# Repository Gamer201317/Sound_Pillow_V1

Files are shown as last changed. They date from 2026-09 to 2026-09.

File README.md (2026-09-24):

# Sound_Pillow_V1

Sound Pillow is an 12 key sounboard with aa rotarty encoder 7 sk mini-e and uses kmk firmware

Features:

12 keys
EC11 Rotary encoder for Volume
7 sk mini-e for a little disco
and aa case in the shape of a pillow 

Cad Model:

the case uses glue to fit everything together at the final stage 
it haas 2 sepaaretly printed pieces the bottom where the pcb slides in to and one top hat you put ovr your key

Schermafbeelding 2026-09-24 143343

make in Tinkercad becausee fusion 360 was to difucult 

Pcb:

Here's my PCB! It was made in KiCad. The silkscreen i found on the internet and aded it 
Schermafbeelding 2026-09-24 143409

this is the schematic

Schermafbeelding 2026-09-24 143421

and this is the pcb

and the next time i'm doing something like this i would like to cleaan the schematic up a little bit more

Firmware Overview

This hackpad uses kmk firmware for everything 
the rotary encoder changes thee volume and i didn't use the button
The 12 keys act as f13-f24 and i use https://www.voicemod.net/ as the software  so i can use the macropad as a soundboard  in discord 
and the leds are there for a little disco

Bom 

-12x Cherry MX Switches
12x DSA Keycaps
-2x M3x16mm SHCS Bolts
-5x 1N4148 DO-35 Diodes.
-7x sk mini-e LEDs
-1x EC11 Rotary Encoder
-1x XIAO RP2040
-1x Case (2 printed parts)

and if you're wondering why there is a hole in the top right of the case that's so you can add an acrylic plate or just watch the components

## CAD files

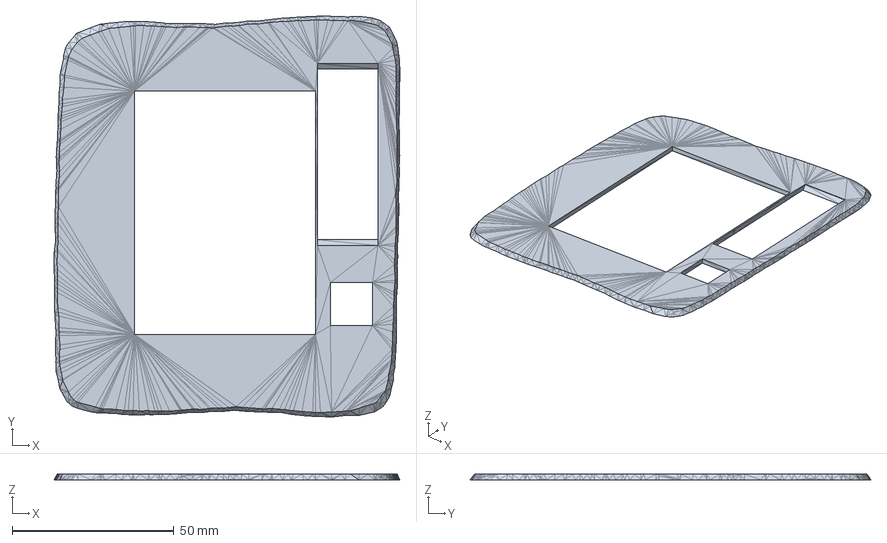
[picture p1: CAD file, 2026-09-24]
Production/Sound_Pillow_Middle.step
106.9 x 123.9 x 1.80 mm

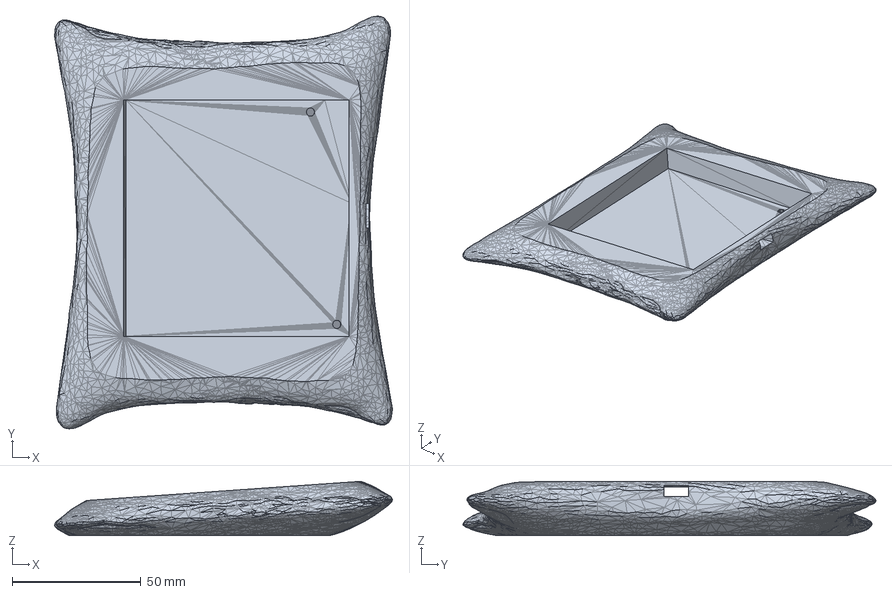
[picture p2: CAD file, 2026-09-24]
Production/Sound_Pillow_Bottom.step
131.2 x 160.1 x 21.1 mm

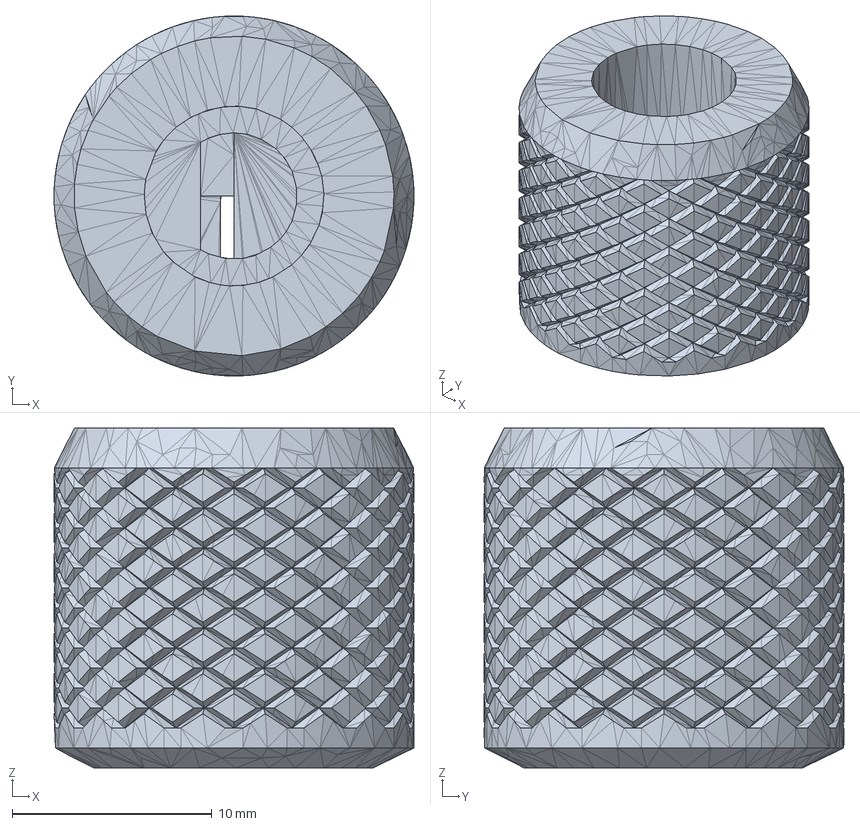
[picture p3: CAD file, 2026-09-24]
Production/Hack Pad Screw.step
18.0 x 18.0 x 17.0 mm
STEP translator 7.5 1.1
STEP translator 7.5 1.2

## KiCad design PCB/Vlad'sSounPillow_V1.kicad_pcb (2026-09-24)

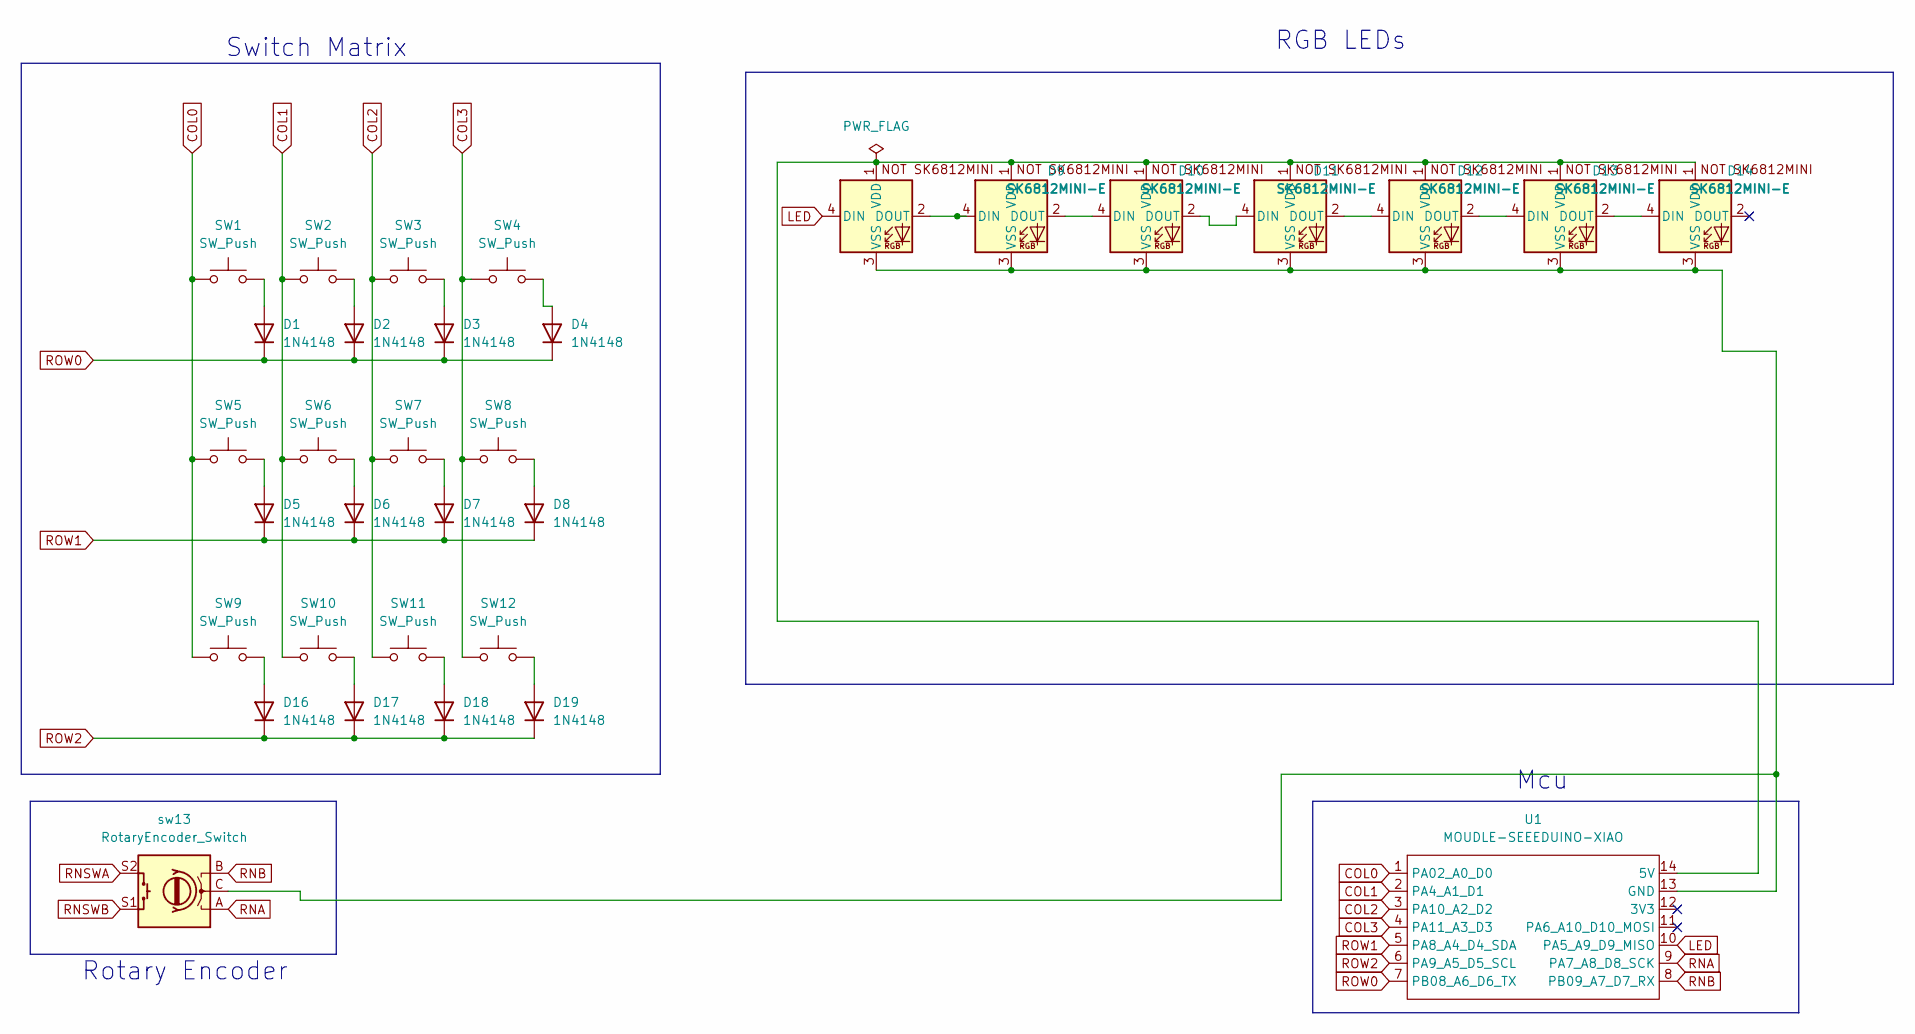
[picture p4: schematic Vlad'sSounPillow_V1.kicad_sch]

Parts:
D1, D2, D3, D4, D5, D6, D7, D8, D16, D17, D18, D19: 1N4148; D_DO-35_SOD27_P7.62mm_Horizontal
D9, D10, D11, D12, D13, D14, D15: SK6812MINI-E; SK6812MINI-E_fixed
SW1, SW2, SW3, SW4, SW5, SW6, SW7, SW8, SW9, SW10, SW11, SW12: SW_Push; SW_Cherry_MX_1.00u_PCB
U1: MOUDLE-SEEEDUINO-XIAO; XIAO-Generic-Hybrid-14P-2.54-21X17.8MM
sw13: RotaryEncoder_Switch; RotaryEncoder_Alps_EC11E-Switch_Vertical_H20mm

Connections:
COL0: SW1.1, SW5.1, SW9.1, U1.1 (PA02_A0_D0)
COL1: SW2.1, SW6.1, SW10.1, U1.2 (PA4_A1_D1)
COL2: SW3.1, SW7.1, SW11.1, U1.3 (PA10_A2_D2)
COL3: SW4.1, SW8.1, SW12.1, U1.4 (PA11_A3_D3)
LED: D9.4 (DIN), U1.10 (PA5_A9_D9_MISO)
unnamed: D1.2 (A), SW1.2
unnamed: D2.2 (A), SW2.2
unnamed: D3.2 (A), SW3.2
unnamed: D4.2 (A), SW4.2
unnamed: D5.2 (A), SW5.2
unnamed: D6.2 (A), SW6.2
unnamed: D7.2 (A), SW7.2
unnamed: D8.2 (A), SW8.2
unnamed: D9.2 (DOUT), D10.4 (DIN)
unnamed: D10.2 (DOUT), D11.4 (DIN)
unnamed: D9.1 (VDD), D10.1 (VDD), D11.1 (VDD), D12.1 (VDD), D13.1 (VDD), D14.1 (VDD), D15.1 (VDD), U1.14 (5V)
unnamed: D9.3 (VSS), D10.3 (VSS), D11.3 (VSS), D12.3 (VSS), D13.3 (VSS), D14.3 (VSS), D15.3 (VSS), U1.13 (GND), sw13.C
unnamed: D11.2 (DOUT), D12.4 (DIN)
unnamed: D12.2 (DOUT), D13.4 (DIN)
unnamed: D13.2 (DOUT), D14.4 (DIN)
unnamed: D14.2 (DOUT), D15.4 (DIN)
unnamed: D16.2 (A), SW9.2
unnamed: D17.2 (A), SW10.2
unnamed: D18.2 (A), SW11.2
unnamed: D19.2 (A), SW12.2
RNA: U1.9 (PA7_A8_D8_SCK), sw13.A
RNB: U1.8 (PB09_A7_D7_RX), sw13.B
RNSWA: sw13.S2
RNSWB: sw13.S1
ROW0: D1.1 (K), D2.1 (K), D3.1 (K), D4.1 (K), U1.7 (PB08_A6_D6_TX)
ROW1: D5.1 (K), D6.1 (K), D7.1 (K), D8.1 (K), U1.5 (PA8_A4_D4_SDA)
ROW2: D16.1 (K), D17.1 (K), D18.1 (K), D19.1 (K), U1.6 (PA9_A5_D5_SCL)

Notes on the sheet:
RGB LEDs
Switch Matrix
Mcu
Rotary Encoder

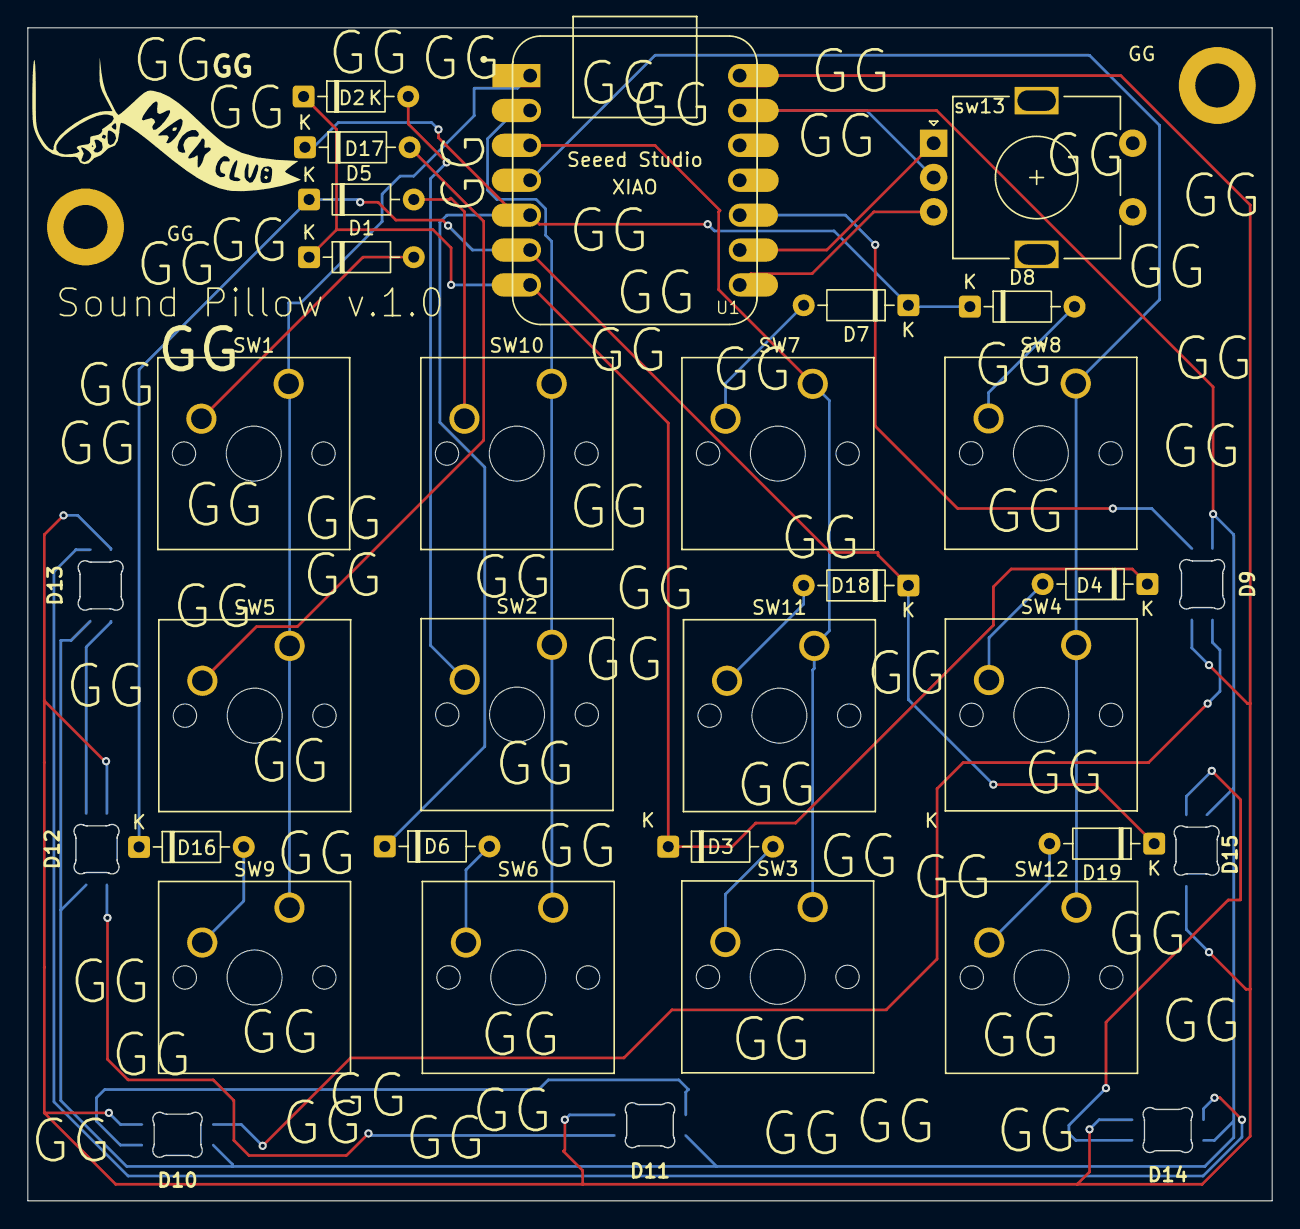
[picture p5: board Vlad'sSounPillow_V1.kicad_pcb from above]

Board: 2 copper layers, 90.6 x 85.4 mm, 36 parts (0 on the bottom side), 30 nets.

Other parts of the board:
GG: M3 screw; MountingHole_3.2mm_M3_DIN965_Pad
GG#2: LOGO
GG#3: M3 screw; MountingHole_3.2mm_M3_DIN965_Pad

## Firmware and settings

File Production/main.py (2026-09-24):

# Sound Pillow
# KMK firmware
# XIAO RP2040
#
# 12 keys:
# F13 - F24
#
# Rotary encoder:
# clockwise  = Volume Up
# counterclockwise = Volume Down
#
# 7x SK6812MINI-E:
# rainbow animation
#
# LED visual order:
# D9 -> D15 -> D14 -> D11 -> D10 -> D12 -> D13

import board

from kmk.kmk_keyboard import KMKKeyboard
from kmk.keys import KC
from kmk.scanners import DiodeOrientation
from kmk.modules.encoder import EncoderHandler
from kmk.extensions.RGB import RGB


keyboard = KMKKeyboard()


# ============================================================
# MATRIX
# ============================================================

keyboard.col_pins = (
    board.D0,
    board.D1,
    board.D2,
    board.D3,
)

keyboard.row_pins = (
    board.D4,
    board.D5,
    board.D6,
)

keyboard.diode_orientation = DiodeOrientation.COL2ROW


# ============================================================
# KEYMAP
# ============================================================

keyboard.keymap = [
    [
        KC.F13, KC.F14, KC.F15, KC.F16,
        KC.F17, KC.F18, KC.F19, KC.F20,
        KC.F21, KC.F22, KC.F23, KC.F24,
    ]
]


# ============================================================
# ROTARY ENCODER
# ============================================================

encoder_handler = EncoderHandler()

encoder_handler.pins = (
    (board.D7, board.D8, None),
)

encoder_handler.map = [
    (
        (KC.VOLU, KC.VOLD),
    ),
]

keyboard.modules.append(encoder_handler)


# ============================================================
# RGB / SK6812MINI-E
# ============================================================

rgb = RGB(
    pixel_pin=board.D9,
    num_pixels=7,
    rgb_order=(1, 0, 2),
)

rgb.effect = "rainbow"

rgb.animation_mode = 1

rgb.brightness = 0.25

keyboard.extensions.append(rgb)


# ============================================================
# START
# ============================================================

if __name__ == "__main__":
    keyboard.go()
